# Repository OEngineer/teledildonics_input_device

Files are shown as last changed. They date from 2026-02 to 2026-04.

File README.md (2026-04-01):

# The (as yet unnamed) Teledildonic Input Device
## What it is
A phallic-shaped capacitive touch input device with nine sensors spaced along its length.  It is built around an [Unexpected Maker TinyS3](https://unexpectedmaker.com/shop.html#!/TinyS3/p/577100914) (ESP32-S3), nine 3D-printed electrode spacers threaded onto an M6 rod, and a small LiPo battery — all assembled into an enclosure made of 3D-printed parts.

The finished assembly must be covered with a non-conductive layer at least 1mm thick. I used adhesive-wall heat-shrink tubing for this (and will use condoms with it for insertion, as the heat-shrink tubing is not known to be body-safe). A better alternative would be to use body-safe silicone.

The nine electrodes are bare loops of tinned wire wound around the outside of each spacer.  Each is connected to one of the ESP32-S3's capacitive-touch GPIO pins.  When the device is touched, gripped, or inserted, the capacitance on the covered electrodes increases and the firmware converts those changes into the metrics described below.

A pushbutton mounted on the side of the base wakes the device from deep-sleep.

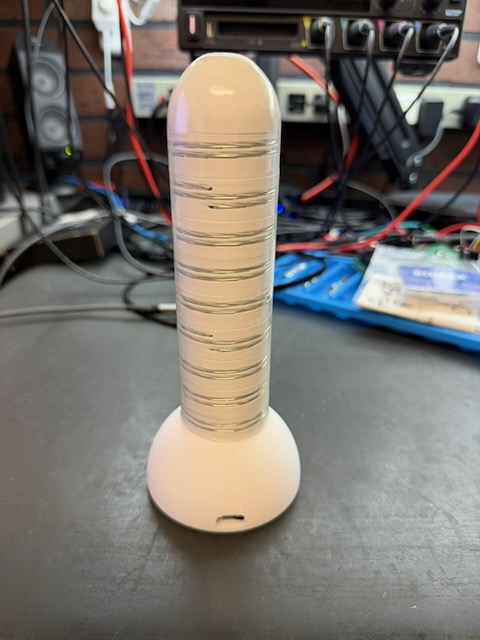
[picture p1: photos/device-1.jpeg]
Complete device

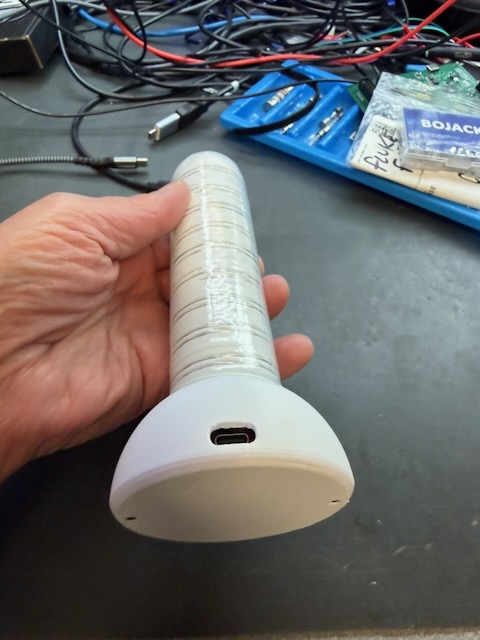
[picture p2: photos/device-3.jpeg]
device bottom view

## What it does
The firmware continuously reads all nine touch electrodes and derives three summary values, each expressed as percentages (0-100):

| Value | Meaning |
|---|---|
| **insertion** | How many sensors are engaged, and how strongly. Rises toward 100 as more of the shaft is covered or pressure increases. |
| **focus** | How concentrated the activity is. High (near 100) when only one or two sensors are active; zero when all sensors are equally active or when there is no activity. |
| **center** | Weighted-average position of touch activity along the shaft: 0 = base, 100 = tip. Returns 0 when focus is 0 (no activity or uniform activity). |

Raw readings are normalized per-sensor using a two-phase calibration that captures each sensor's idle baseline and peak touch range.  Calibration data is stored in `/calibration.json` on the device's flash filesystem and survives reboots.

## The firmware
The firmware is written in MicroPython running on the TinyS3.  The relevant source files are in `src/` here, and in the root of the flash filesystem on the device:

| File | Purpose |
|---|---|
| `touch_sensor.py` | `MultiTouchSensor` — configures the nine `TouchPad` objects and provides synchronous (`read`) and async (`read_async`) raw-value reads. |
| `touch_analysis.py` | `TouchAnalyzer` — wraps `MultiTouchSensor` with two-phase calibration, per-sensor normalization, and the `insertion`, `focus`, and `center_of_activity` metrics. |
| `stroke_detector.py` | `StrokeDetector` — detects stroke peaks and troughs in the insertion signal using EMA smoothing and direction-reversal logic; drives event-based OSSM position commands. |
| `ble_remote.py` | `OSSMRemote` — BLE client that scans for an OSSM device, connects, sends initial settings, and streams position commands at detected stroke extrema. |
| `config.py` | Pin assignments, touch threshold, sleep timeout, BLE initial settings, stroke detector tuning, and shared helpers. |
| `main.py` | Entry point: prompts for calibration if none is saved, then runs the touch output loop, BLE task, and idle sleep monitor concurrently. |
| `queue.py` | Peter Hinch's asyncio Queue |

### Calibration
Calibration is two-phase and interactive:

1. **Rest phase** (default 3 s) — set the device on a surface and do not touch it.  The firmware records the idle baseline for each sensor.
2. **Handle phase** (default 10 s) — pick up and handle the device naturally, making sure to touch the full length of the shaft.  The firmware records the peak touch response for each sensor.

The resulting offset and scale per sensor are saved to `/calibration.json`.  Delete that file (or answer `y` at startup with no calibration present) to recalibrate.

To re-calibrate, connect to the USB, wake the device, and enter Ctrl-C in the REPL. Then type:
```
>>> recalibrate()
```
Follow the instructions for re-calibration.
Then enter Ctrl-D to reboot. Disconnect the cable.

### Async design
All sensor reads use `asyncio.sleep_ms` between individual pin reads, so the loop never blocks for more than ~30 ms per pin.  The main output loop runs at approximately 100 ms intervals and yields control between iterations, making it easy to integrate with other async tasks.

Three async tasks run concurrently: `run_output` (touch sensing and metrics), `ble_task` (BLE streaming to an OSSM device), and `idle_monitor` (deep-sleep watchdog).

### BLE output (OSSM remote)
`ble_remote.py` implements `OSSMRemote`, a BLE central that drives an [OSSM](https://discuss.kink3d.com/t/ossm/369) sex machine using the standard OSSM BLE service (UUID `522b443a-4f53-534d-0001-420badbabe69`, compatible with OSSM Rust firmware v3.0+).

On each connection cycle it:
1. Scans for a device advertising the OSSM service UUID (5-second scan window).
2. Connects and discovers the command characteristic.
3. Sends any initial settings as `set:<key>:<value>` commands (default: `speed=0`, `depth=0`, `stroke=100`).
4. Sends `go:streaming` to activate streaming mode.
5. Streams `stream:<position>:<interval_ms>` commands — but only at detected stroke peaks, troughs, and sustained-stillness events, using `StrokeDetector` to determine when and what to send.

The `interval_ms` in each stream command is derived from the elapsed time since the last emit (clamped to `STROKE_MIN_MOVE_MS`–2000 ms), so OSSM moves at the same speed as the input device.  The first command after connect uses `STROKE_INITIAL_MOVE_MS` (2000 ms) for a gentle start.

If the connection drops, `ble_task` waits 3 seconds and then retries from the scan step.

#### Stroke detection

`stroke_detector.py` implements `StrokeDetector`, which converts the continuous `insertion` signal (0–100) into discrete events at stroke extrema (peaks and troughs) and sustained-stillness points.  It applies EMA smoothing (`STROKE_EMA_ALPHA`), then emits whenever:

- the smoothed position reverses direction by at least `STROKE_MIN_AMPLITUDE` units (direction-change extremum), or
- the position stays within `STROKE_STOPPED_THRESHOLD` units for `STROKE_STOPPED_WINDOW` consecutive samples (stillness event).

This event-driven approach lets OSSM match the actual stroke rhythm rather than streaming at a fixed rate.

#### Testing BLE without hardware

`test/ossm_ble_sim.py` is a desktop Python script that acts as a fake OSSM peripheral.  It advertises the same OSSM GATT service UUID and prints every command written to the characteristic, so you can verify `ble_remote.py` behaviour without a real OSSM device.

```bash
pip install bless
python test/ossm_ble_sim.py
```

Requires Linux (BlueZ with `bluetoothd` running) or macOS (CoreBluetooth).  `bless` >= 0.2.1.

### Deep sleep
The device enters ESP32 deep sleep after 30 seconds of no touch activity (insertion below threshold). Currently the default threshold is 20%. Activity resets the idle timer; inactivity causes `idle_monitor` to call `machine.deepsleep()`.

Wakeup is via a momentary button on **GPIO 21** (an RTC-capable pin), wired active-low (shorts to GND when pressed).  The internal pull-up is held active during deep sleep (`hold=True`) so no external resistor is required.  On waking, the firmware logs the wakeup reason and resumes normally — calibration data survives deep sleep because it is stored on the flash filesystem.

## Building
### Parts required
  - 3D printed parts (see below)
  - 155mm length of M6 threaded rod
  - 2x M6 threaded inserts
  - 2x 1.5mm x 6mm long plastic screws
  - Unexpected Maker TinyS3
  - Pushbutton with 7mm mounting hole
  - Flexible stranded hookup wire, ideally solderable and in different colors (I used 24AWG silicone wire)
  - Li-poly cell (I used a 400mAh one that fit; check space available in model or 3D print)
  - Solid tinned or silver-coated wire, 20-22 AWG. Make sure that this is solderable (much "craft wire" is enameled and so not easily soldered).
  - Length of 1.5" (39mm) diameter adhesive-wall 3:1 heat-shrink tubing (optional, for holding everything together and helping make it waterproof.)

    [Here is the one I used](https://www.amazon.com/dp/B07SD47JM8)

    Or you could just coat the whole thing with body-safe silicone.
  - Hot glue, UV resin, or other filler for the top of the heat-shrink tubing (if you're using it).
### Tools and supplies required
  - Soldering iron and solder
  - Heat setting tool for threaded inserts (or use your soldering iron)
  - Wire stripper
  - Needlenose pliers
  - Low- or medium-strength thread locker (green or blue)
  - Binder clip to hold the spacers in place during assembly (or you can use masking tape pieces)
  - If you're using the heat shrink tubing around the shaft:
    - Heat gun
    - Scissors
    - Hot glue gun, UV curing lamp, or other tools for the end filler.
### 3D Print
Print the following parts (models in the `hardware/` directory):
  - 9x `spacer`
  - 1x `top`
  - 1x `base`
  - 1x `base_cover`
### Attach threaded inserts
Use a soldering iron or similar to melt the threaded inserts into the `top` and `base` parts.
### Making the sensors
Make 9 sensors:
  - Insert the end of your solid wire into one of the two holes on the side of the `spacer`.
  - Twist the end into a loop. You will be soldering to this loop.
  - Pass the wire around the spacer, keeping it tight
  - Bend the wire sharply so it can pass through the other hole.
  - Cut the wire about 2cm from the bend
  - Insert the cut end into the hole
  - Bend it over or twist it into a loop
### Final Assembly
Start at the base.
  - Thread the M5 rod into the base. If you have threadlocker, use a dab of it here.
  - For each of the nine sensors:
    - Slide the next `spacer` (wired with solid wire) over the threaded rod (it helps to glue the first one to the base).
    - Rotate it so that the four holes line up with the ones in the base and other sensors and the ends of the solid wire are positioned 90 degrees clockwise from the prior one. This will ensure that a single one of the 4 channels won't get over-filled with hookup wire.
    - Clip the binder clip onto the threaded rod just above the spacer. This will keep it in place while you're working on it. If you don't have a binder clip, you can use a piece of masking tape to stick it to the prior sensor.
    - Solder the stripped end of a piece of hookup wire to the end of the solid wire
    - Cut the hookup wire long enough to reach the base cover plus 3cm or so
    - Strip the cut end of the hookup wire about 2-3mm.
    - Insert the hookup wire into the next GPIO pad of the TinyS3 (start at GPIO0)
    - Solder the wire onto the TinyS3 board

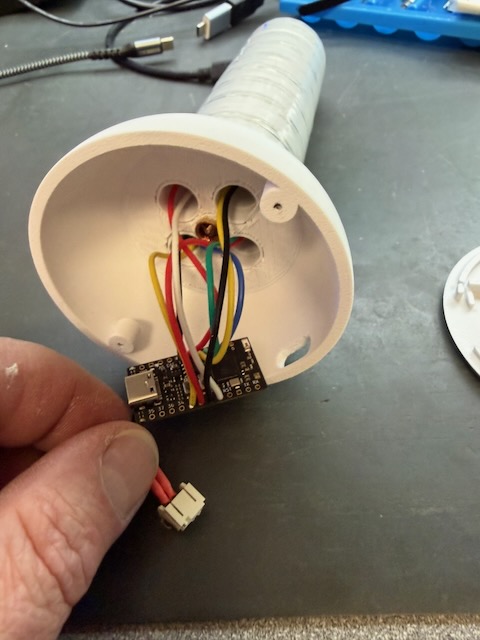
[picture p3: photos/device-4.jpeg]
board assembly


  - Add a wired JST connector for your battery if you're using one. Solder the wires under the board to the battery contacts.
  - Solder two wires to the pushbutton, then mount it in the hole.
  - Connect the pushbutton wires to GND and GPIO21 (see src/config.py)

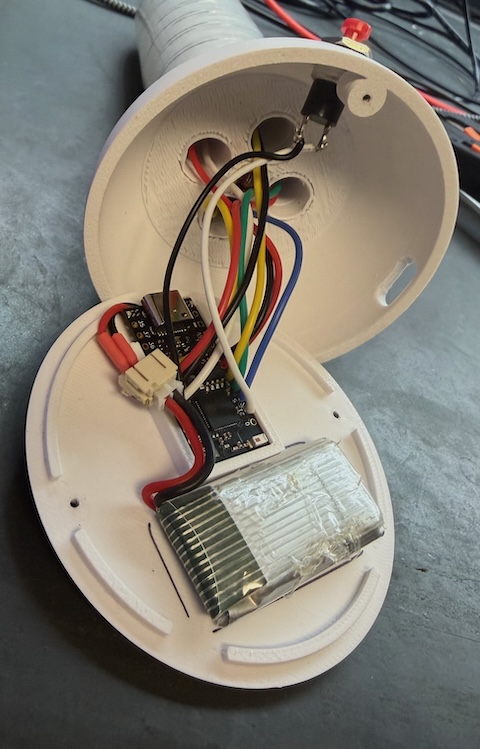
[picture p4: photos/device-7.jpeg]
bottom cover detail

  - Thread the `top` on, using threadlocker if you want.
  - If you're using heat-shrink tubing:
    - Cut a piece of tubing somewhat longer than the distance from the base to the tip. It will shrink quite a bit when heated, so be generous. You will trim the excess later.
    - Heat the heat shrink tubing evenly, making sure that the bottom is flush with the base and the top shrinks evenly.
    - While the tubing is still soft, trim the excess on the end with a pair of scissors or scalpel.
    - Fill in the bare spot at the end with hot melt glue, UV resin, or other substance so it's flush with the cut end of the heat shrink tubing.
## Installing the firmware
  - Install MicroPython from the [micropython.org website](https://micropython.org/download/UM_TINYS3/)
  - Install `mpremote` (or you can use `rshell`, `Thonny`, etc.)
  - Copy the contents of `src/` (and `src/lib`) to the root of the filesystem:
    ```bash
    mpremote cp -r src/* :/
    ```
  - The first time you run the firmware, you will be prompted to create a calibration file.
  - You can remove '/calibration.json' from your flash filesystem to be prompted again.
  - Test by running ```mpremote repl```:
  ```bash
  [OEngineer/teledildonics_input_device] % mpremote repl
  Connected to MicroPython at /dev/cu.usbmodem3144101
  Use Ctrl-] or Ctrl-x to exit this shell
  <ctrl-D>
  MPY: soft reboot
  No valid calibration found; using defaults.
  Do you want to calibrate now (y/n)?y
  Phase 1 (3 s): set the device down - do not touch it.
  Press Enter to start rest phase...
  Press Enter to start handling phase...
  Phase 2 (10 s): stroke, fondle, and handle the device now.
  Calibration done.
    offsets: [25714, 25038, 26755, 26214, 24746, 26703, 26815, 29324, 28949]
    scales:  [7910, 10332, 11986, 12678, 11635, 9600, 11263, 11661, 13998]
  Calibration saved.
  focus: 0 insertion: 88 center: 51
  focus: 0 insertion: 89 center: 52
  ...
  ```
## Using it
I recommend coating the device with body-safe silicone after it's working, or at least using a condom around it if you're going to be inserting it.

## Power consumption
I've measured this at about 189µA during deep-sleep, and about 67mA during power-on (while connected via BLE).

### License
Licensed under the CERN Open Hardware Licence Version 2 - Strongly Reciprocal

See LICENSE.txt

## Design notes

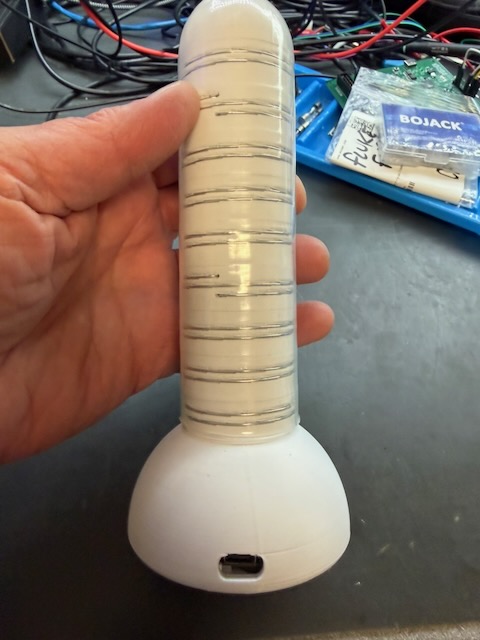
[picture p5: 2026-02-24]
photos/device-2.jpeg

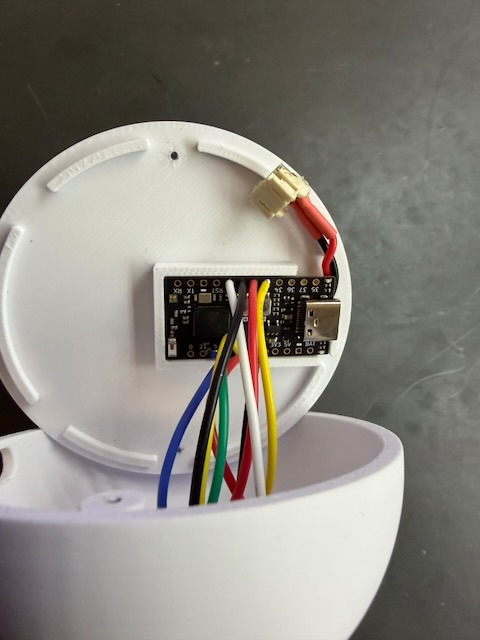
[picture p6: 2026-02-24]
photos/device-6.jpeg

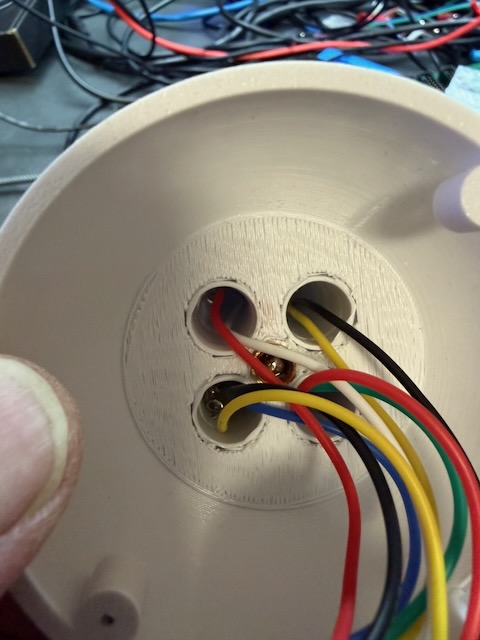
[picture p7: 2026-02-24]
photos/device-5.jpeg

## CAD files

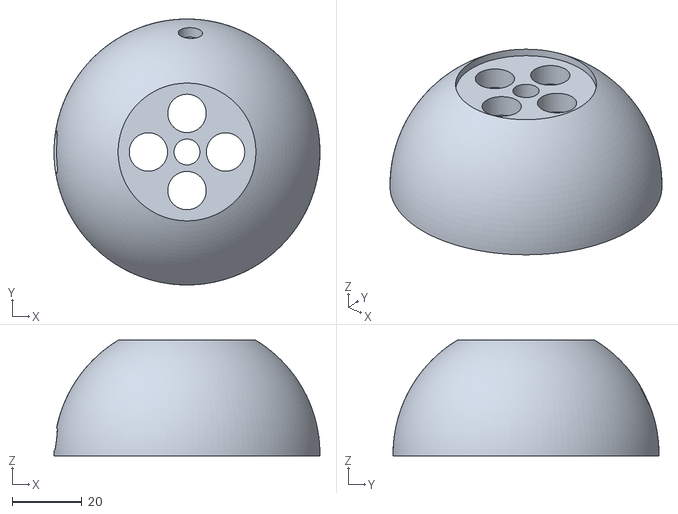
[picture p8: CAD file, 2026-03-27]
hardware/Base.stl
76.2 x 76.2 x 33.1

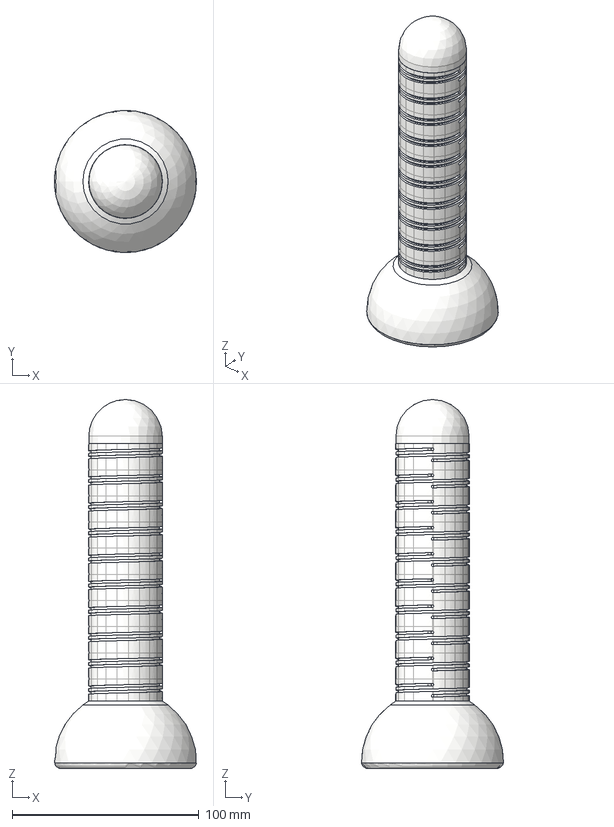
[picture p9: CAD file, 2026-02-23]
hardware/js2.step
76.2 x 76.1 x 197.6 mm
top
Base
spacer x 10
TinyS3_P8_V2_AT2450AT18B100 PCB
base cover
400maH li cell

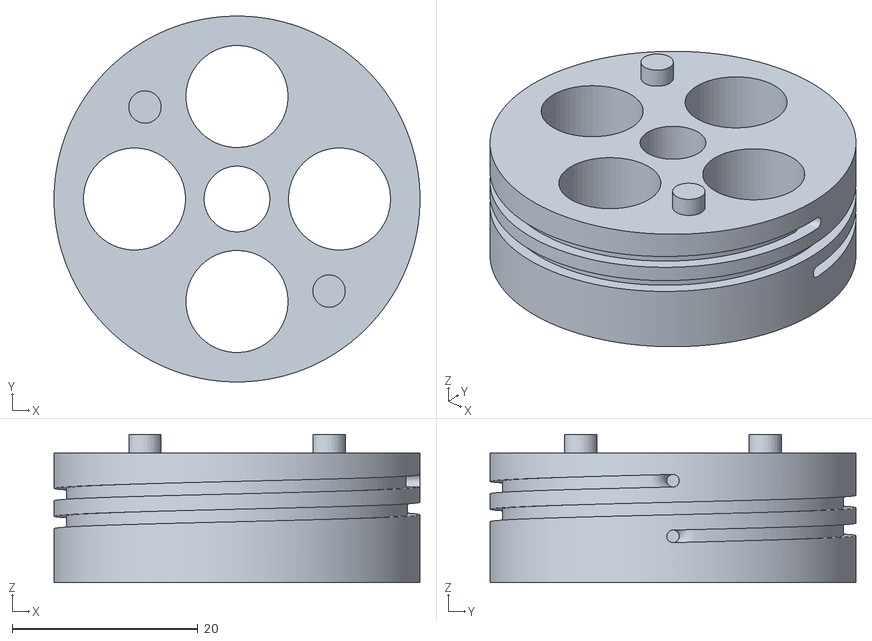
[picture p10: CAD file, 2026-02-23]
hardware/spacer.stl
39.4 x 39.4 x 16.0

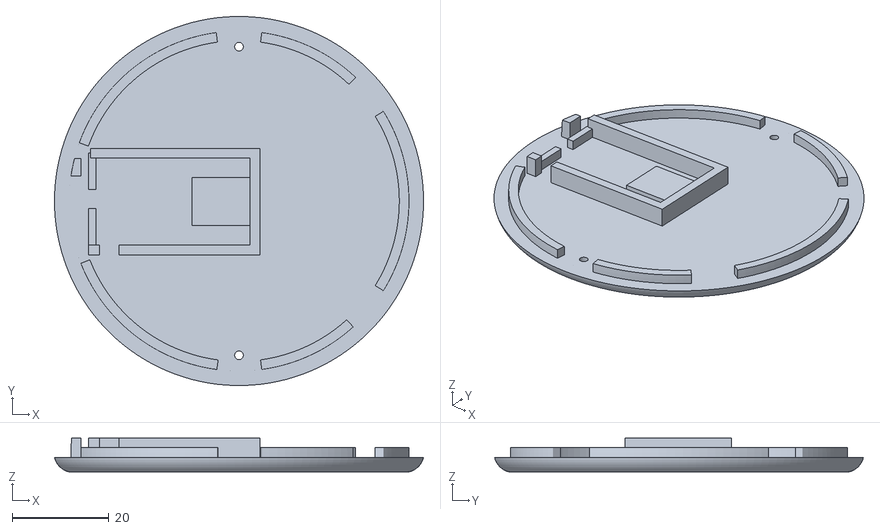
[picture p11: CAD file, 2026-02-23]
hardware/base cover.stl
76.2 x 76.2 x 7.00

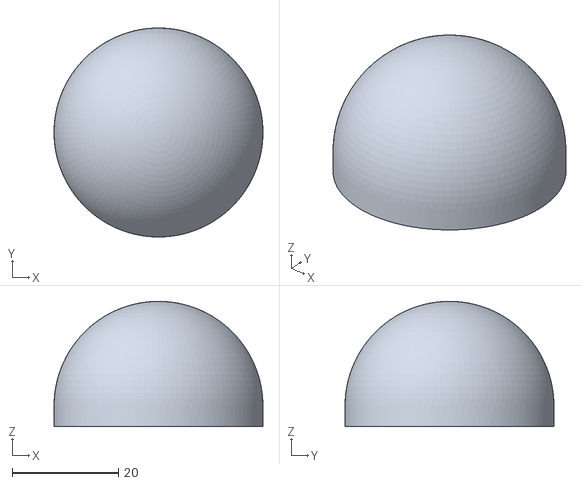
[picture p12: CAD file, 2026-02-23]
hardware/top.stl
39.4 x 39.4 x 23.6

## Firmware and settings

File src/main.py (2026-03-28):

import asyncio, machine, esp32
from machine import Pin
from time import ticks_ms, ticks_diff
import touch_sensor, touch_analysis
from config import (
    WAKEUP_PIN, SLEEP_TIMEOUT_MS, BLE_SPEED, BLE_DEPTH, BLE_STROKE,
    STROKE_EMA_ALPHA, STROKE_MIN_AMPLITUDE,
    STROKE_STOPPED_WINDOW, STROKE_STOPPED_THRESHOLD,
    STROKE_PEAK_HISTORY, STROKE_POLL_MS, STROKE_MIN_MOVE_MS, STROKE_INITIAL_MOVE_MS,
    STROKE_LOG,
)
from touch_analysis import ACTIVE_THRESHOLD
from ble_remote import OSSMRemote, RECONNECT_DELAY_MS
from stroke_detector import StrokeDetector
from queue import Queue, QueueFull

# IO21: RTC pin, internal pull-up; button shorts to GND to wake from deep sleep.
# hold=True ensures that pull-up is maintained in deep-sleep.
_wakeup_pin = Pin(WAKEUP_PIN, Pin.IN, Pin.PULL_UP, hold=True)

# Log wakeup reason once on boot.
_reset_cause = machine.reset_cause()
if _reset_cause == machine.DEEPSLEEP_RESET:
    print("Woke from deep sleep (button press).")
else:
    print(f"Cold boot (reset cause {_reset_cause}).")

s = touch_sensor.MultiTouchSensor()
a = touch_analysis.TouchAnalyzer(s)

# Shared state: run_output writes here; ble_task reads from it.
_last_analyzed = {}

if not a._calibrated:
    yn = input("Do you want to calibrate now (y/n)?")
    if yn.lower() in ("y", "yes"):
        asyncio.run(a.calibrate())

# Shared idle-tracking state.
_last_active_ms = ticks_ms()

def recalibrate():
    asyncio.run(a.calibrate())

def _record_activity():
    global _last_active_ms
    _last_active_ms = ticks_ms()


def _enter_deepsleep():
    print(f"Entering deep sleep. Press IO{WAKEUP_PIN} button to wake.")
    # EXT0 wakeup: wake when the pin is driven low (button press pulls to GND).
    esp32.wake_on_ext0(_wakeup_pin, 0)
    machine.deepsleep()


async def idle_monitor():
    """Sleep the device after SLEEP_TIMEOUT_MS of no touch activity."""
    while True:
        await asyncio.sleep_ms(1000)
        if ticks_diff(ticks_ms(), _last_active_ms) >= SLEEP_TIMEOUT_MS:
            _enter_deepsleep()


async def run_output():
    global _last_analyzed
    while True:
        analyzed = await a.analyze()
        _last_analyzed = analyzed
        if analyzed["insertion"] >= ACTIVE_THRESHOLD:
            _record_activity()
        print(
            f"focus: {analyzed['focus'] * 100:.0f} insertion: {analyzed['insertion'] * 100:.0f} center: {analyzed['center'] * 100:.0f}"
        )
        await asyncio.sleep_ms(100)


_stroke_queue = Queue(maxsize=4)


async def stroke_task():
    """Detect stroke extrema and enqueue (position, interval_ms) tuples."""
    detector = StrokeDetector(
        STROKE_EMA_ALPHA, STROKE_MIN_AMPLITUDE,
        STROKE_STOPPED_WINDOW, STROKE_STOPPED_THRESHOLD,
        STROKE_PEAK_HISTORY,
    )
    last_emit_ms = ticks_ms()
    prev_elapsed = None

    t0 = ticks_ms()
    while True:
        raw = int(_last_analyzed.get("insertion", 0) * 100)
        emit, pos = detector.update(raw)
        if STROKE_LOG:
            print(f"S,{ticks_diff(ticks_ms(), t0)},{raw},{detector.smoothed:.2f},{pos if emit else -1}")
        if emit:
            now = ticks_ms()
            elapsed = ticks_diff(now, last_emit_ms)
            if prev_elapsed is None:
                interval_ms = STROKE_INITIAL_MOVE_MS
            else:
                interval_ms = max(STROKE_MIN_MOVE_MS, min(prev_elapsed, 2000))
            prev_elapsed = elapsed
            last_emit_ms = now
            try:
                _stroke_queue.put_nowait((pos, interval_ms))
            except QueueFull:
                pass  # BLE not consuming; drop this event
        await asyncio.sleep_ms(STROKE_POLL_MS)


async def ble_task():
    remote = OSSMRemote({"speed": BLE_SPEED, "depth": BLE_DEPTH, "stroke": BLE_STROKE})
    while True:
        await remote.connect()
        if remote.connected:
            # Drain stale events queued while disconnected.
            while not _stroke_queue.empty():
                _stroke_queue.get_nowait()
            await remote.run(_stroke_queue)
        await asyncio.sleep_ms(RECONNECT_DELAY_MS)


async def main():
    asyncio.create_task(idle_monitor())
    asyncio.create_task(stroke_task())
    asyncio.create_task(ble_task())
    await run_output()


asyncio.run(main())

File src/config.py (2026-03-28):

import asyncio
from machine import Pin

# BLE initial settings sent to OSSM before streaming (0-100, None to skip)
BLE_SPEED = 100
BLE_DEPTH = 100 
BLE_STROKE = 100     # Scale 1:1 for 160mm typical OSSM stroke length

# Power management
WAKEUP_PIN = 21          # RTC-capable GPIO for EXT0 deep-sleep wakeup (active-low button)
SLEEP_TIMEOUT_MS = 30_000  # idle time before deep sleep (ms)

# Stroke detection (see stroke_detector.py)
STROKE_EMA_ALPHA         = 0.25  # smoothing factor (lower = smoother, more lag)
STROKE_MIN_AMPLITUDE     = 8     # min 0-100 change from last extremum to count as a stroke
STROKE_STOPPED_WINDOW    = 5     # consecutive STROKE_POLL_MS samples within threshold -> stopped
STROKE_STOPPED_THRESHOLD = 2     # position units (0-100) defining "not moving"
STROKE_PEAK_HISTORY      = 10    # samples of EMA history to search for true peak/trough
STROKE_POLL_MS           = 100   # detector poll interval; matches sensor update rate
STROKE_MIN_MOVE_MS       = 300   # floor for stream interval_ms sent to OSSM
STROKE_INITIAL_MOVE_MS   = 2000  # interval_ms for the first emit after connect (gentle start)
STROKE_MOTION_MARGIN_MS  = 50    # extra wait after interval_ms before consuming next queue item
STROKE_LOG               = False # print CSV lines for plotting (t_ms,raw,ema,emit)

def set_global_exception():
    def handle_exception(loop, context):
        import sys
        sys.print_exception(context["exception"])
        sys.exit()
    loop = asyncio.get_event_loop()
    loop.set_exception_handler(handle_exception)

boot_pin = Pin(0, Pin.IN, Pin.PULL_UP)

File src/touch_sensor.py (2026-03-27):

import asyncio
from machine import TouchPad, Pin
from micropython import const

_NUM_PINS = const(9)
_ALL_PINS = range(1, _NUM_PINS + 1)


async def _read_pin_async(pin):
    await asyncio.sleep_ms(30)
    return pin.read()


class MultiTouchSensor:
    def __init__(self, pins=_ALL_PINS):
        self._num_pins = len(pins)
        self._touch_pins = [None] * self.num_pins
        # Configure all the touch pins (1-9) on the ESP32 TinyS3 board
        for i, pin_num in enumerate(pins):
            self._touch_pins[i] = TouchPad(Pin(pin_num))

    def read(self):
        # Read all the touch pins
        return [pin.read() for pin in self._touch_pins]

    async def read_async(self):
        # Read all the touch pins
        retval = [] * self.num_pins
        for pin in self._touch_pins:
            retval.append(await _read_pin_async(pin))
        return retval

    @property
    def num_pins(self):
        return self._num_pins

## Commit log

2025-06-19 WIP: dealing with stuck readings
    [config.py, touch_sensor.py]
2026-02-23 Add hardware files.
    [Base.stl, base cover.stl, js2.f3z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]
2026-03-24 Add wakeup button on IO21.
2026-03-25 Add hold=True to wakeup pin.
2026-03-27 Update README.md to agree with new code and pushbutton addition.
    Update STEP file and base STL for addition of pushbutton.
    [Base.stl, js2.f3z]
2026-03-28 Fix BLE transmission by using a different peak detector.
    Add tool to plot output (for tuning).
    [config.py, main.py, stroke_detector.py]
